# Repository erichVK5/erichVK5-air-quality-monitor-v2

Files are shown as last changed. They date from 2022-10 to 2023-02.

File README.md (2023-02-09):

# erichVK5-air-quality-monitor-v2
A leaner version of the original erichVK5 air quality monitor

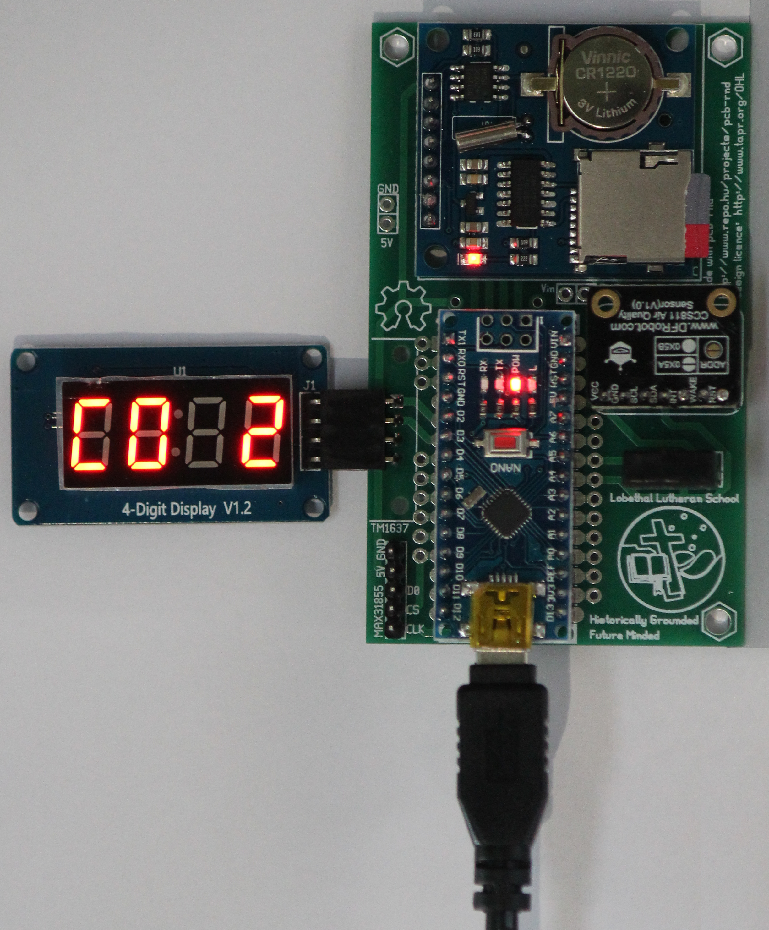
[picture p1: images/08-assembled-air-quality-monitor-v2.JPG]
assembled board


The PCB and accompanying software allow the CCS811 sensor to be used to monitor CO2 and total volatile organic compounds, and the AM2320 sensor allows humidity and temperature to be recorded as well.

This is a leaner version of https://github.com/erichVK5/erichVK5-air-quality-monitor, achieving a significant cost reduction by using an Arduino nano and a compact Deek Robot 8122 RTC/SD board on a custom PCB which also mounts the DF Robot CCS811 CO2/VOC sensor board and the AM2320 temperature/humidity sensor. 

current schematic

The revised v2 PCB was designed in pcb-rnd and simplifies the connections between the TM1637 display, CCS811 sensor, AM2320 sensor and Arduino Nano. The PCB dimensions have been carefully chosen to allow efficient panelisation on standard panel sizes if ordering larger quantities from PCB suppliers. By mounting the sensors, RTC, data logging and Arduino subassemblies on a single PCB, the build cost can be roughly halved. 

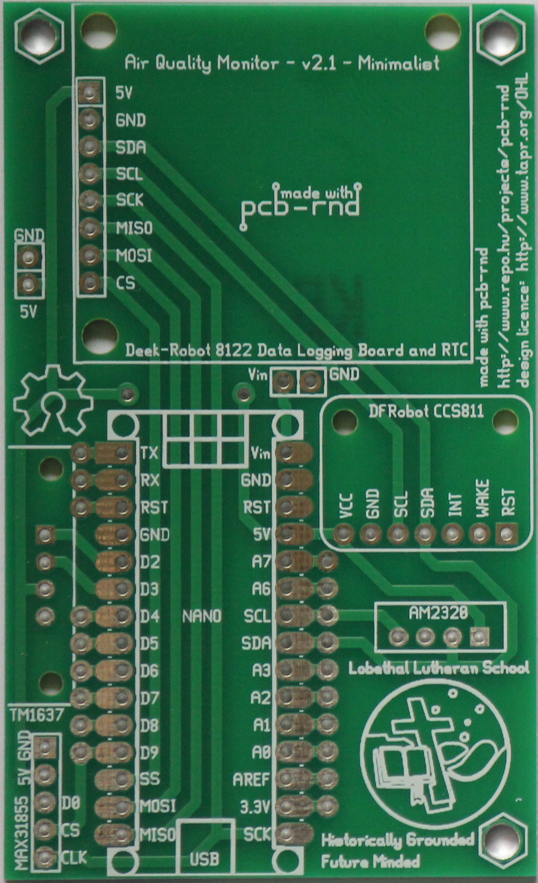
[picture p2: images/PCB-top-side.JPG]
PCB top side

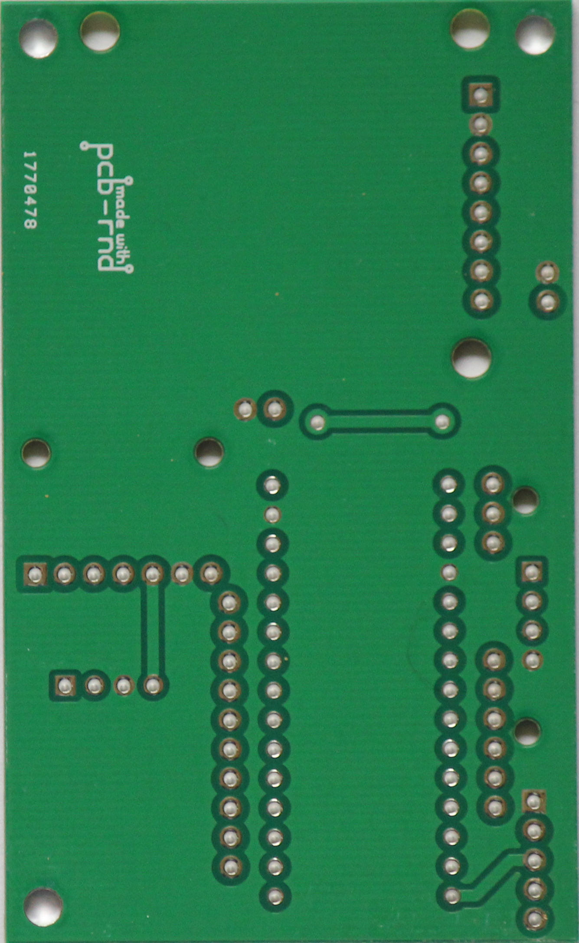
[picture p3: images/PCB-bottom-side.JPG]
PCB bottom side


The board is code compatible with the original air quality monitor, except for the real time clock, which uses a DS1307 instead of a PCF8523. The board has been designed to allow the option of mounting an Arduino Nano Every, but care must be taken if there are plans to use an external 5V power supply for the board, as the Arduino Nano Every, unlike the Arduino Nano, can apparently backfeed 5V down an inserted USB cable to a host.

Low cost data logging air quality monitors remain useful in educational and community settings to provide a qualitative indication of air quality over time. In particular, CO2 levels can be a useful proxy for air turnover in built environments, and by extension, inform measures that seek to reduce the risk of persisting airborne pathogens. The utility of CO2 as a proxy for airborne pathogen loads will be affected by sources of combustion or fermentation (i.e. processes producing CO2 in addition to people) in the indoor space, and by the use of air purifying devices, such as those circulating air through suitable filters.

The PCB has a footprint allowing connection to an inexpensive TM1637 based four digit LED display for the display of readings, but with suitable code modification, other display options are possible. For example, here is a build using a MAX7219 based 8x32 LED Matrix:

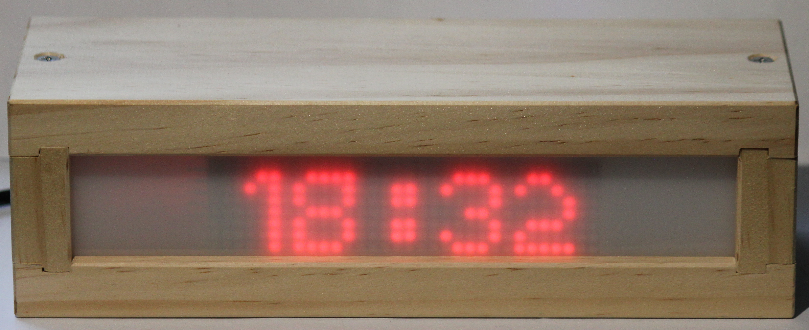
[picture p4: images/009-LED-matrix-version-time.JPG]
LED matrix version


After assembly of the PCB headers and sub-boards is complete, following the pictorial guide in the images subdirectory, a battery can be installed on the Deek Robot 8122 datalogging board. The DS1307 clock example code available within the arduino library manager can then be used to set the current time.

In addition to taking and displaying readings every 10 seconds, the accompanying code will write time stamped readings to an SD card every three minutes.

After reset, if all goes well, an initial flash screen "LLS" should appear, after which readings will be displayed sequentially, with new readings being taken every 10 seconds. Every three minutes, cached readings are written to the SD card.

The Deek Robot 8122 datalogging board requires a CR1220 battery for the DS1307 real time clock, and will require a FAT16 or FAT32 formatted SD card of between 32MB and 32GB in size.

The unit should be powered down before inserting or removing the SD card.

Data logs are written in CSV format, with sequential naming starting with LLSAQM00.CSV

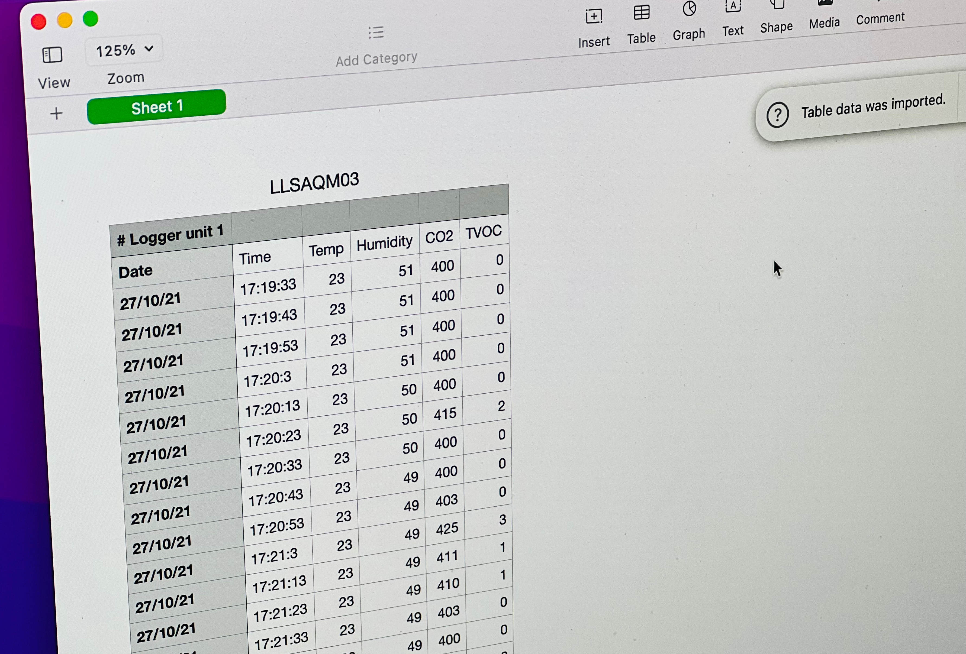
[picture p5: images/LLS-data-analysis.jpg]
data from the SD card


During operation, updated readings are displayed sequentially on the 4 digit LED display.

- Temperature readings in Centigrade are preceded by "t" on the LED display
- Humidity readings in percent are preceded by "h" on the LED display
- Carbon dioxide readings in ppm (parts per million) are preceded by "CO2" on the LED display
- Total volatile organic compound readings in ppb (parts per billion) are preceded by "tvoc" on the LED display

The code also streams results over USB as a serial device, allowing readings to be viewed as they are collected in a serial monitor in real time.

It is recommended that the CCS811 be given a 48 hour initial burn in period and be allowed 20 minutes for the sensor to warm up to provide reliable readings thereafter.

The v2 PCB layout can be opened in pcb-rnd, and gerbers for the shield have been provided in a zip file to allow ordering from the usual online PCB suppliers.

The schematic for the v2 board is essentially identical to that of the original version, with SCL using A5 and SDA using A4 on the Arduino Nano.

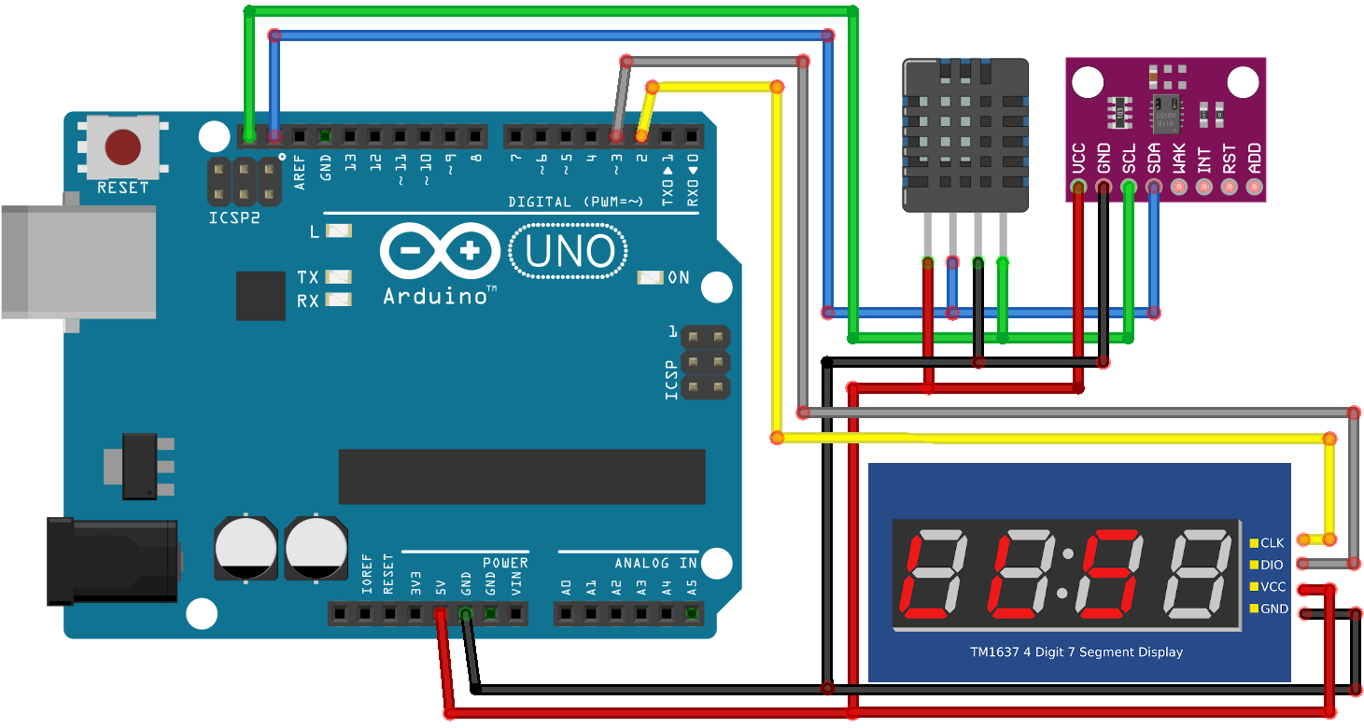
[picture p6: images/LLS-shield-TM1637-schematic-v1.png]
Shield schematic using TM1637 display


For data transfers to and from the SD card, the Deek Robot 8122 datalogging board uses SPI on the following Arduino Uno pins:

- SCK
- MISO
- MOSI
- D10 as CS (chip select)

For real time clock operations, the Deek Robot 8122 datalogging board also shares the i2c bus with with the CCS811 and AM2320 sensors, using the following pins:

- SDA(A4)
- SCL(A5)

This leaves multiple pins free on the Arduino Nano if code customisation is needed, such as for on/off signals for fans or building ventilation systems. Spare pins on the arduino nano have been broken out to pads, to allow wiring to other actuators, sensors or switches.

The v2 PCB also has pads to connect external Vin to the Arduino Nano. Builders must ensure that the overall power demands of their display and assembled unit will fall within that which can be provided by the Arduino Nano voltage regulator.

ALternatively, there is also footprint provided on the v2 PCB for a connector for provision of an external 5V supply to the 5V rail (instead of relying on USB for power) that feeds the peripherals and Arduino Nano 5V pin, BUT(!)... although a standard Arduino Nano can be powered via the 5V pin from an external source without backfeeding the voltage down the USB cable to the host, an Arduino Nano Every will apparently allow the power supplied via the 5V pin to go up the USB cable to a host, if connected.

The DS1307 real time clock seems to be a little sensitive to power supply noise. If there are issues with the clock not updating, it may be worth trying some filtering on the power supply, and/or some decoupling capacitors to smoothe the supply.

Unlike the Adafruit data logging shield which includes 10k pullup resistors for the SDA and SCL lines, they may not be as strong or may be absent on the Deek Robot 8122 datalogging board. Accordingly, for reliable operation with the clock, DF Robot and AM2320 sensors all on the same i2c bus, pullup resistors (4k7 or 10k) should be added to link Vcc to the SDA and SCL lines. A revised version of the board (v2.1) has footprints for the addition of pullup resistors if needed. 

The v2 PCB also has a footprint to allow the use of a MAX31855 thermocouple, if builders are keen to experiment with temperature measurement, display and control of various hot processes.

# LED Matrix clock build

The pins for the MAX31855 thermocouple supply most of the needed connections for an SPI driven display, such as commonly available MAX7219 LED matrices. The example build shown above uses an 8x32 MAX7219 LED matrix instead of the TM1637, connected to GND, 5v, SCK, and D9 for CS on the MAX31855 header, and MOSI (accessed on the RTC/SD board header).

A simple code example has been provided which provides some of the functionality of the TM1637 build but using a MAX7219 based 8x32 LED Matrix, along with code to read A0-A3 connected button presses to adjust the time if required. The main differences are that it does not stream results to serial, display of tvoc has not been implemented, and it does not log data to the SD card.

It displays temperature for 4 seconds, humidity for 4 seconds, CO2 for 4 seconds, and then the time for 48 seconds, after which the cycle repeats.

The LED matrix based build was conceived of as more of an example of how an inexpensive clock with environmental sensing could also be implemented with the v2 PCB, rather than simply another version of the same data logging air quality monitor. The aluminium bracket used for the switches and DC socket was surplus tile edging, and the white diffuser panel was found in a discarded fax/printer.

Again, it is worth noting that the DS1307 real time clock seems sensitive to power supply noise, so it may be worth trying some filtering on the power supply, and/or some decoupling capacitors to smoothe the supply if glitches are noted.

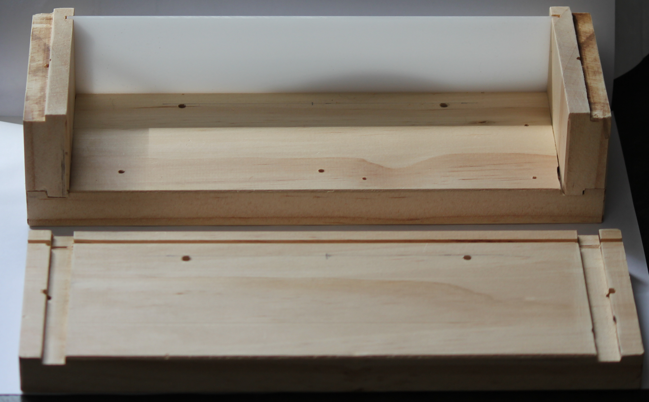
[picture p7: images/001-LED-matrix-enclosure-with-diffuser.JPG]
LED Matrix enclosure and diffuser

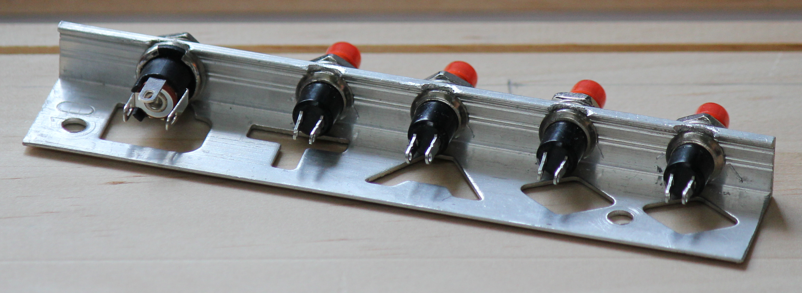
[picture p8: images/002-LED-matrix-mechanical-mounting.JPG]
LED Matrix mechanical mountings

LED Matrix mounting details
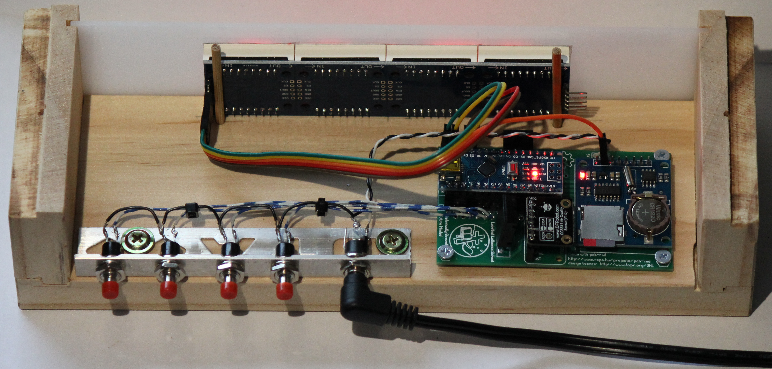
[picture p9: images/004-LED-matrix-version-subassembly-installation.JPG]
LED Matrix subassembly installation

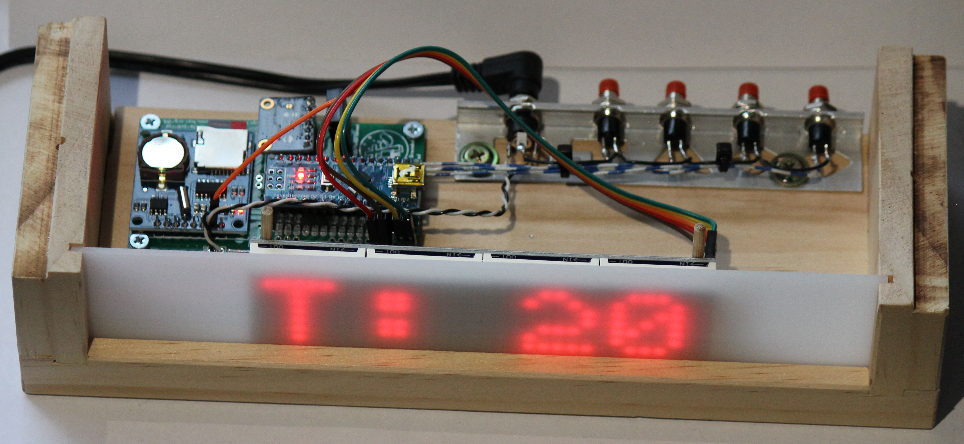
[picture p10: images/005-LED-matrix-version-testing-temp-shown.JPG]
LED Matrix testing temp

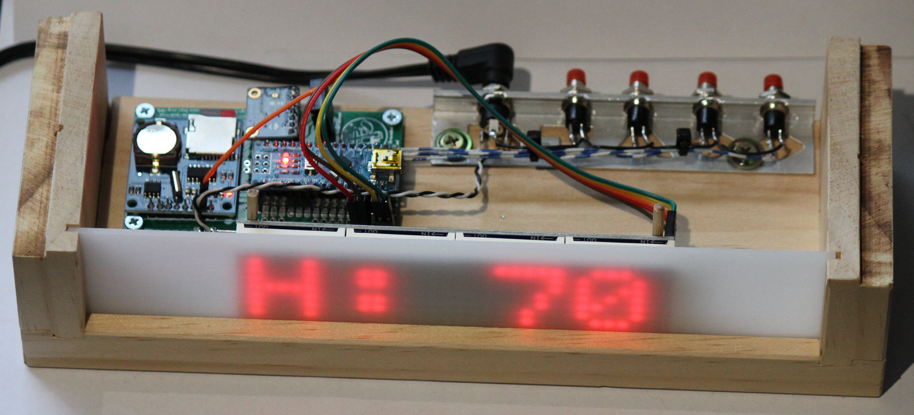
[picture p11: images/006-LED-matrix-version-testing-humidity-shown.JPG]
LED Matrix testing humidity

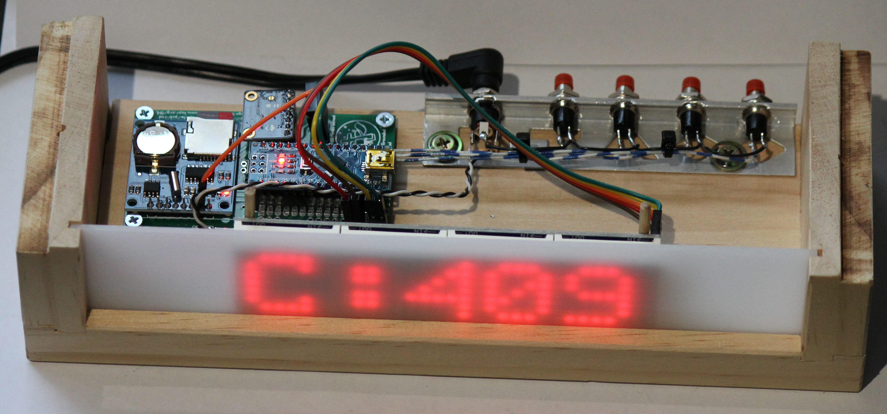
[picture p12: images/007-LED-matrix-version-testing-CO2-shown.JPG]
LED Matrix testing C02

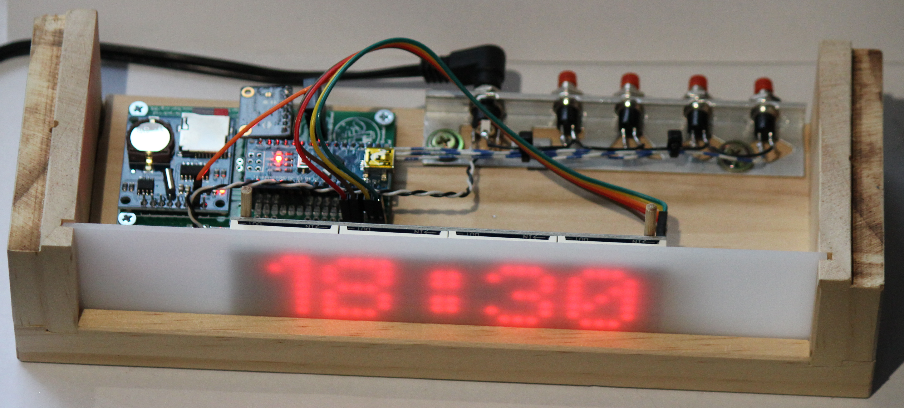
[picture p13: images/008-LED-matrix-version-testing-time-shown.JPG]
LED Matrix testing time


# Clock Drift Adjustment

The latest version of the clock code has the necessary code to adjust the real time clock (RTC) by one second every X seconds; but this requires the user to determine how fast the clock is running fast or slow.

In the prototype build, the clock ran 5.75 seconds fast every 24 hours. This was found by noting the clock ran 8 minutes 26 seconds (= 506 seconds) fast over 88 days. This allowed the number of seconds per day fast or slow (5.75 seconds), to be calculated.

Given that there are 86,400 seconds in a day, this enabled the simple calculation 86400/5.75 showing that the RTC runs one second fast every 15026.0869 seconds.

The code simply waits until 15026 seconds (the amount is defined at compile time in the code) have elapsed before subtracting one second from the RTC. It then waits 2 seconds to avoid an endless time correcting loop. If you can calculate the drift, you can now adjust the clock.

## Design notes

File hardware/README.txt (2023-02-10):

Schematic is in sch-rnd format ( see www.repo.hu/projects/sch-rnd )
PCB layout is in pcb-rnd format ( see www.repo.hu/projects/pcb-rnd )

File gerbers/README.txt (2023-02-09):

The gerbers include
- footprints for a pair of i2c bus pullup resistors
- decoupling capcitors for smoothing the 5V power rail
- increased ground plane pullback from the edges to facilitate panelisation

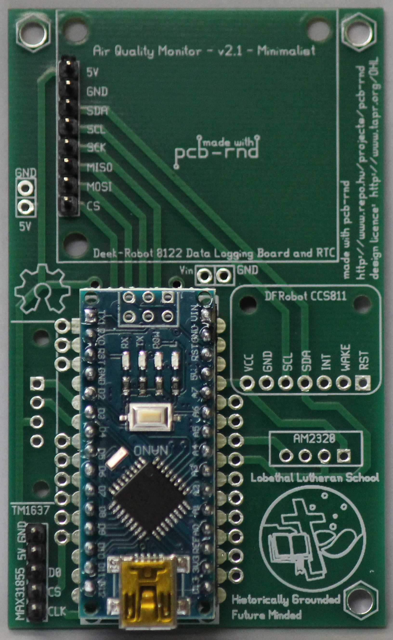
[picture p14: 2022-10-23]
images/03-add-RTC-SD-header-pins.JPG

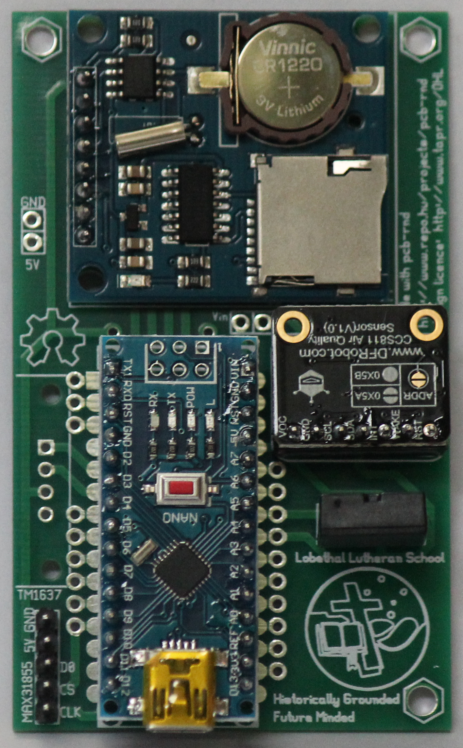
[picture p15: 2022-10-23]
images/06-add-Temp-Humidity-sensor.JPG

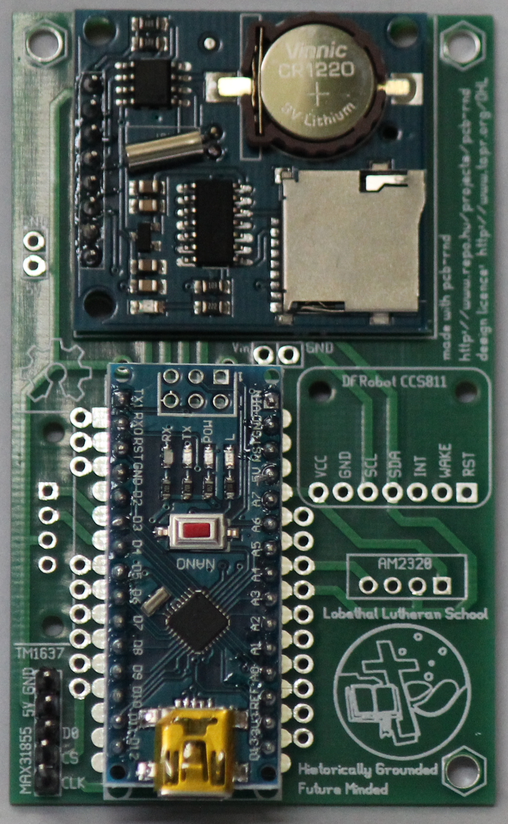
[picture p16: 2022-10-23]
images/04-add-RTC-SD-board.JPG

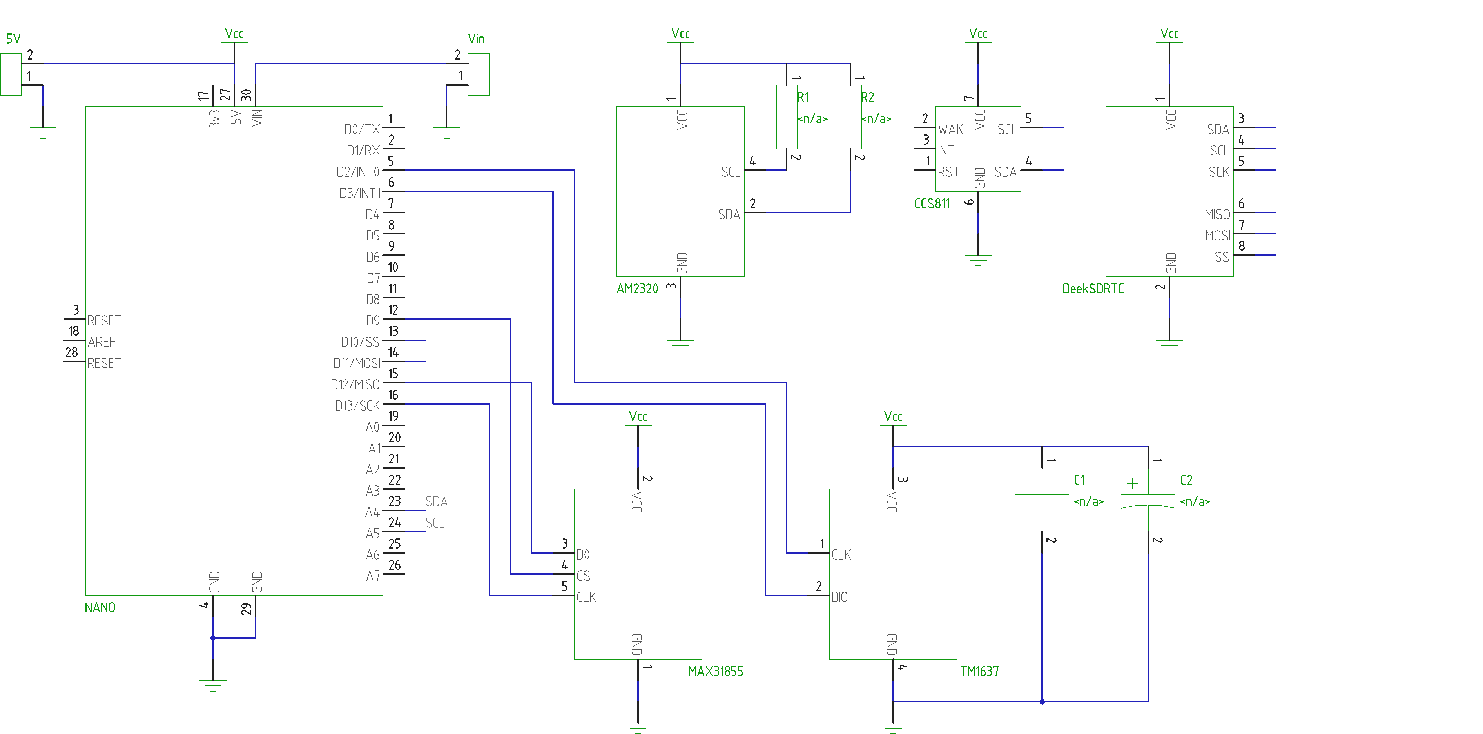
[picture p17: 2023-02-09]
images/erichVK5-AQM-v2-2.png

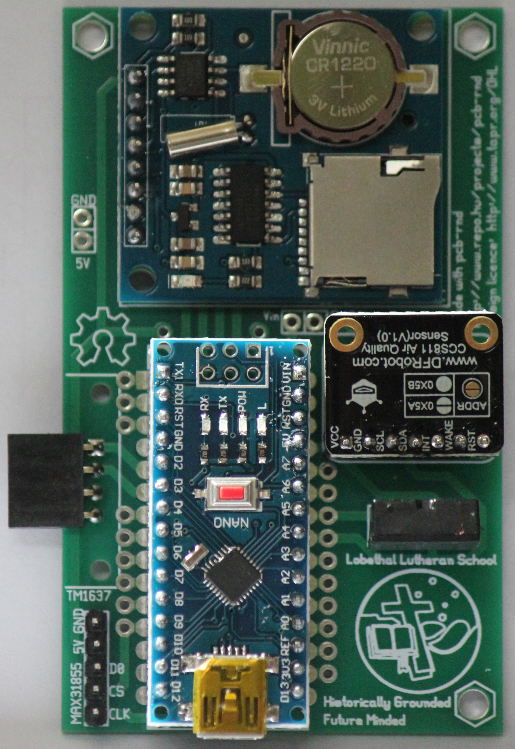
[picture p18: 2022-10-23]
images/07-add-TM1637-display-header.JPG

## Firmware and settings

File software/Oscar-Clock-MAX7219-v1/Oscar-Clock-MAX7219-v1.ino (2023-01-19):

/*
 *
 *   Copyright (C) 2022 Erich S. Heinzle
 *   
 *   drawString and drawSprite routines based on examples by Bartosz Bielawski
 *   included in LEDMatrixDriver library
 *
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
 */
 
#include "Arduino.h"
#include <LEDMatrixDriver.hpp>
#include "Adafruit_Sensor.h"
#include "Adafruit_AM2320.h"
#include "Adafruit_CCS811.h"
#include "RTClib.h"
//#include "Wire.h"
#include "SD.h"

// Pin 10 CS required by SD card code
#define CHIP_SELECT 10

// Uncomment according to your hardware type
#define HARDWARE_TYPE MD_MAX72XX::FC16_HW
//#define HARDWARE_TYPE MD_MAX72XX::GENERIC_HW

// Defining size, and output pins
#define MAX_DEVICES 4

const uint8_t LEDMATRIX_CS_PIN = 9;

const int LEDMATRIX_SEGMENTS = 4;
const int LEDMATRIX_WIDTH = LEDMATRIX_SEGMENTS * 8;

Adafruit_AM2320 am2320 = Adafruit_AM2320();
RTC_DS1307 RTC;
Adafruit_CCS811 ccs811;

// The LEDMatrixDriver class instance
LEDMatrixDriver lmd(LEDMATRIX_SEGMENTS, LEDMATRIX_CS_PIN);


void setup()
{
  pinMode(CHIP_SELECT, OUTPUT);
  pinMode(A0, INPUT_PULLUP);
  pinMode(A1, INPUT_PULLUP);
  pinMode(A2, INPUT_PULLUP);
  pinMode(A3, INPUT_PULLUP);

  lmd.setEnabled(true);
  lmd.setIntensity(0);

  // start sensors
  am2320.begin();
  ccs811.begin();
  // wait for CCS811 startup
  while(!ccs811.available());

  //Wire.begin();
  // check if RTC is working
  RTC.begin();
  if (!RTC.isrunning()) {
    ;
  }
}

/**
 * This draws a sprite to the given position using the width and height supplied (usually 8x8)
 */
void drawSprite(LEDMatrixDriver *lmd, byte* sprite, int x, int y, int width, int height )
{
  // The mask is used to get the column bit from the sprite row
  byte mask = B10000000;

  for( int iy = 0; iy < height; iy++ )
  {
    for( int ix = 0; ix < width; ix++ )
    {
      lmd->setPixel(x + ix, y + iy, (bool)(sprite[iy] & mask ));

      // shift the mask by one pixel to the right
      mask = mask >> 1;
    }

    // reset column mask
    mask = B10000000;
  }
}

/**
 * This function draws a string of the given length to the given position.
 */
void drawString(LEDMatrixDriver *lmd, char* text, int len, int x, int y )
{
  byte font[95][8] = {
                     {0,0,0,0,0,0,0,0}, // SPACE
                     {0x10,0x18,0x18,0x18,0x18,0x00,0x18,0x18}, // EXCL
                     {0x28,0x28,0x08,0x00,0x00,0x00,0x00,0x00}, // QUOT
                     {0x00,0x0a,0x7f,0x14,0x28,0xfe,0x50,0x00}, // #
                     {0x10,0x38,0x54,0x70,0x1c,0x54,0x38,0x10}, // $
                     {0x00,0x60,0x66,0x08,0x10,0x66,0x06,0x00}, // %
                     {0,0,0,0,0,0,0,0}, // &
                     {0x00,0x10,0x18,0x18,0x08,0x00,0x00,0x00}, // '
                     {0x02,0x04,0x08,0x08,0x08,0x08,0x08,0x04}, // (
                     {0x40,0x20,0x10,0x10,0x10,0x10,0x10,0x20}, // )
                     {0x00,0x10,0x54,0x38,0x10,0x38,0x54,0x10}, // *
                     {0x00,0x08,0x08,0x08,0x7f,0x08,0x08,0x08}, // +
                     {0x00,0x00,0x00,0x00,0x00,0x18,0x18,0x08}, // COMMA
                     {0x00,0x00,0x00,0x00,0x7e,0x00,0x00,0x00}, // -
                     {0x00,0x00,0x00,0x00,0x00,0x00,0x06,0x06}, // DOT
                     {0x00,0x04,0x04,0x08,0x10,0x20,0x40,0x40}, // /
                     {0x00,0x38,0x44,0x4c,0x54,0x64,0x44,0x38}, // 0
                     {0x00,0x0c,0x14,0x04,0x04,0x04,0x04,0x04}, // 1
                     {0x00,0x30,0x48,0x04,0x04,0x38,0x40,0x7c}, // 2
                     {0x00,0x38,0x44,0x04,0x18,0x04,0x44,0x38}, // 3
                     {0x00,0x04,0x0c,0x14,0x24,0x7e,0x04,0x04}, // 4
                     {0x00,0x7c,0x40,0x40,0x78,0x04,0x04,0x78}, // 5
                     {0x00,0x38,0x40,0x40,0x78,0x44,0x44,0x38}, // 6
                     {0x00,0x7c,0x04,0x04,0x08,0x08,0x10,0x10}, // 7
                     {0x00,0x3c,0x44,0x44,0x38,0x44,0x44,0x78}, // 8
                     {0x00,0x38,0x44,0x44,0x3c,0x04,0x04,0x78}, // 9
                     {0x00,0x00,0x18,0x18,0x00,0x18,0x18,0x00}, // :
                     {0x00,0x18,0x18,0x00,0x00,0x18,0x18,0x08}, // ;
                     {0x00,0x10,0x20,0x40,0x80,0x40,0x20,0x10}, // <
                     {0x00,0x00,0x7e,0x00,0x00,0xfc,0x00,0x00}, // =
                     {0x00,0x08,0x04,0x02,0x01,0x02,0x04,0x08}, // >
                     {0x00,0x38,0x44,0x04,0x08,0x10,0x00,0x10}, // ?
                     {0x00,0x30,0x48,0xba,0xba,0x84,0x78,0x00}, // @
                     {0x00,0x1c,0x22,0x42,0x42,0x7e,0x42,0x42}, // A
                     {0x00,0x78,0x44,0x44,0x78,0x44,0x44,0x7c}, // B
                     {0x00,0x3c,0x44,0x40,0x40,0x40,0x44,0x3c}, // C
                     {0x00,0x7c,0x42,0x42,0x42,0x42,0x44,0x78}, // D
                     {0x00,0x78,0x40,0x40,0x70,0x40,0x40,0x7c}, // E
                     {0x00,0x7c,0x40,0x40,0x78,0x40,0x40,0x40}, // F
                     {0x00,0x3c,0x40,0x40,0x5c,0x44,0x44,0x78}, // G
                     {0x00,0x44,0x44,0x44,0x7c,0x44,0x44,0x44}, // H
                     {0x00,0x7c,0x10,0x10,0x10,0x10,0x10,0x7e}, // I
                     {0x00,0x7e,0x02,0x02,0x02,0x02,0x04,0x38}, // J
                     {0x00,0x44,0x48,0x50,0x60,0x50,0x48,0x44}, // K
                     {0x00,0x40,0x40,0x40,0x40,0x40,0x40,0x7c}, // L
                     {0x00,0x82,0xc6,0xaa,0x92,0x82,0x82,0x82}, // M
                     {0x00,0x42,0x42,0x62,0x52,0x4a,0x46,0x42}, // N
                     {0x00,0x3c,0x42,0x42,0x42,0x42,0x44,0x38}, // O
                     {0x00,0x78,0x44,0x44,0x48,0x70,0x40,0x40}, // P
                     {0x00,0x3c,0x42,0x42,0x52,0x4a,0x44,0x3a}, // Q
                     {0x00,0x78,0x44,0x44,0x78,0x50,0x48,0x44}, // R
                     {0x00,0x38,0x40,0x40,0x38,0x04,0x04,0x78}, // S
                     {0x00,0x7e,0x10,0x10,0x10,0x10,0x10,0x10}, // T
                     {0x00,0x42,0x42,0x42,0x42,0x42,0x42,0x3e}, // U
                     {0x00,0x42,0x42,0x42,0x42,0x44,0x28,0x10}, // V
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
                      // (the font does not contain any lower case letters. you can add your own.)
  };

  for( int idx = 0; idx < len; idx ++ )
  {
    int c = text[idx] - 32;

    // stop if char is outside visible area
    if( x + idx * 6  > LEDMATRIX_WIDTH )
      return;

    // only draw if char is visible
    if( 8 + x + idx * 6 > 0 )
      drawSprite(lmd, font[c], x + idx * 6, y, 8, 8 );
  }
}

void adjustTime(LEDMatrixDriver *lmd, RTC_DS1307 *rtc, DateTime *dt) {
  int min_orig = dt->minute();
  int hr_orig = dt->hour();
  uint32_t ticks = dt->secondstime();
  int hr = hr_orig;
  int mi = min_orig;
  char strbuf[6]; // hh:mm
  sprintf(strbuf, "Set..");
  int len = strlen(strbuf);
  drawString(lmd, strbuf, len, 0, 0);
  lmd->display();   // Toggle display of the new framebuffer
  delay(1000);
  while (analogRead(A0) < 50) {
    if (analogRead(A3) < 50 && analogRead(A1) < 50) {
      mi = (mi - 1)%60;
    } else if (analogRead(A3) < 50 && analogRead(A1) > 500) {
      mi = (mi + 1)%60;    
    } else if (analogRead(A2) < 50 && analogRead(A1) < 50) {
      hr = (hr - 1)%24;
    } else if (analogRead(A2) < 50 && analogRead(A1) > 500) {
      hr = (hr + 1)%24;    
    }
    delay(200);
    sprintf(strbuf, "%02d%c%02d", hr, (true ? ':' : ' '), mi);
    int len = strlen(strbuf);
    drawString(lmd, strbuf, len, 0, 0);
  }
  rtc->adjust(DateTime(ticks+3600*(hr-hr_orig) + 60*(mi-min_orig)));
  delay(200);
  *dt = rtc->now();
}

void loop()
{
  char strbuf[6]; // hh:mm
  int len;
  int current_minute;
  int previous_minute = 0;
  uint16_t co2;
  DateTime dt = RTC.now();

  // these variable are used for adjusting the error in the RTC
  // you will need to see how many seconds slow or fast it runs over an extended
  // period to calculate the number of seconds per day it runs fast or slow
  // in the prototype, it ran 8 min 26 seconds (= 506 seconds) fast over 88 days
  // i.e. 5.75 seconds per day fast
  uint32_t ticks_orig = dt.unixtime();
  uint32_t ticks_current = 0;
  uint16_t ticks_since_adjustment = 0;
  uint16_t ticks_per_adjustment = 15026; // if running 5.75 seconds fast per day
  int ticks_adjustment = 1;              // i.e 5.75 seconds every 86,400 seconds ( = day)
  
  int use_sensors = 1;
  int adjust_error = 0; // set this to 1 if you plan to adjust RTC drift error
  
  while (1)
  {
    dt = RTC.now();
    current_minute = dt.minute();
    ticks_current = dt.unixtime();
    if (adjust_error) {
      ticks_since_adjustment = (ticks_current - ticks_orig)%ticks_per_adjustment;
      if (ticks_since_adjustment >= (ticks_per_adjustment - 3)) { // allow a 2 second window
        RTC.adjust(DateTime(ticks_current - ticks_adjustment));
        delay(3000); // avoid endless readjustment in a loop
      }
    }
    delay(200);
    if (current_minute != previous_minute)
    {
      if (use_sensors) {
       sprintf(strbuf, "T: %02d", (int)am2320.readTemperature());
       len = strlen(strbuf);
       drawString(&lmd, strbuf, len, 0, 0);
       lmd.display();   // Toggle display of the new framebuffer
       delay(4000);
       sprintf(strbuf, "H: %02d", (int)am2320.readHumidity());
       len = strlen(strbuf);
       drawString(&lmd, strbuf, len, 0, 0);
       lmd.display();   // Toggle display of the new framebuffer
       delay(4000);
       if(ccs811.available()){
         if(!ccs811.readData()){
           co2 = (uint16_t)ccs811.geteCO2();
           if (co2 < 1000) {
             sprintf(strbuf, "C:%03d", co2);
           } else {
             sprintf(strbuf, "C%04d", co2);
           }
           len = strlen(strbuf);
           drawString(&lmd, strbuf, len, 0, 0);
           lmd.display();   // Toggle display of the new framebuffer
           delay(4000);
         }
        }
      }
      sprintf(strbuf, "%02d%c%02d", dt.hour(), (true ? ':' : ' '), current_minute);
      len = strlen(strbuf);
      drawString(&lmd, strbuf, len, 0, 0);
      lmd.display();   // Toggle display of the new framebuffer
      delay(5000);
      previous_minute = current_minute;
    }
    // now to see if the time needs adjusting
    // this only works if buttons are attached to A0...A3
    if (0 && analogRead(A0) < 50) {
      delay(50); // software debouncing 
      if (analogRead(A0) < 50) {
        sprintf(strbuf, "A0..");
        len = strlen(strbuf);
        drawString(&lmd, strbuf, len, 0, 0);
        lmd.display();
        delay(500);
        adjustTime(&lmd, &RTC, &dt);
        current_minute = dt.minute();
        sprintf(strbuf, "%02d%c%02d", dt.hour(), (true ? ':' : ' '), dt.minute());
        len = strlen(strbuf);
        drawString(&lmd, strbuf, len, 0, 0);
        lmd.display();   // Toggle display of the new framebuffer
      }
    }
  }
}

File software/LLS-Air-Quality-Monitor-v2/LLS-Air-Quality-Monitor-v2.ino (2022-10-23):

/*
 *
 *   Copyright (C) 2021 Erich S. Heinzle
 *   Website https://github.com/Lobethal-Lutheran-School/
 *   
 *   Lobethal Lutheran School - "Historically Grounded, Future Minded"
 *
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
 */
 
#include "Arduino.h"
#include "TM1637Display.h"
#include "Adafruit_Sensor.h"
#include "Adafruit_AM2320.h"
#include "Adafruit_CCS811.h"
#include "RTClib.h"
#include "Wire.h"
#include "SD.h"

// TM1637 Module connection pins (Digital Pins)
#define CLK 2
#define DIO 3
// Pin 10 CS required by SD card code
#define CHIP_SELECT 10

// Time (milliseconds) between sensor readings
// need 8*DISPLAY_PAUSE < MS_BETWEEN_SAMPLES 
#define DISPLAY_PAUSE 1200 

// NB caching more than 18 sample sets tends to exceed
// dynamic RAM needs of code running on atmega328
// so writing batches of 18 samples to SD is about right
//
#define MS_BETWEEN_SAMPLES 10000
// samples per minute = 60000/MS_BETWEEN_SAMPLES 
#define SAMPLES_PER_WRITE 18
// minutes between sample writes to SD = SAMPLES_PER_WRITE/samples per minute 

// Struct used for storing time stamp for a set of readings
typedef struct time_stamp_t {
  uint8_t Year;
  uint8_t Month;
  uint8_t Day;
  uint8_t Hour;
  uint8_t Min;
  uint8_t Sec;
};  

// Struct used for caching sets of readings between SD card writes
typedef struct ring_buffer_t {
  time_stamp_t time_stamp[SAMPLES_PER_WRITE];
  uint8_t temp[SAMPLES_PER_WRITE];     // essentially guaranteed to be less than 256
  uint8_t humidity[SAMPLES_PER_WRITE]; // less than 101 by definition
  uint16_t co2[SAMPLES_PER_WRITE];     // usually exceeds 256
  uint16_t tvoc[SAMPLES_PER_WRITE];    // may exceed 256
  uint8_t index;
};

// four digit definition for "LLS"
const uint8_t SEG_LLS[] = {
  SEG_D | SEG_E | SEG_F,                           // L
  SEG_D | SEG_E | SEG_F,                           // L
  SEG_A | SEG_C | SEG_D | SEG_F | SEG_G,           // S
  0
  };

// four digit definition for "CO2"
const uint8_t SEG_CO2[] = {
  SEG_A | SEG_D | SEG_E | SEG_F,                   // C
  SEG_A | SEG_B | SEG_C | SEG_D | SEG_E | SEG_F,   // O
  0,
  SEG_A | SEG_B | SEG_D | SEG_E | SEG_G            // 2
  };

// four digit definition for "t" - temperature
const uint8_t SEG_T[] = {
  SEG_D | SEG_E | SEG_F | SEG_G,                   // t
  0,
  0,
  0
  };

// four digit definition for "h" - humidity
const uint8_t SEG_H[] = {
  SEG_C | SEG_E | SEG_E | SEG_F | SEG_G,           // h
  0,
  0,
  0
  };

// four digit definition for "TVOC" - total VOCs
const uint8_t SEG_TVOC[] = {
  SEG_D | SEG_E | SEG_F | SEG_G,                   // t
  SEG_C | SEG_D | SEG_E,                           // v
  SEG_C | SEG_D | SEG_E | SEG_G,                   // o
  SEG_D | SEG_E | SEG_G,                           // c
  };

// four digit definition for "SD" - writes to SD card
const uint8_t SEG_SD[] = {
  SEG_A | SEG_C | SEG_D | SEG_F | SEG_G,           // S
  SEG_B | SEG_C | SEG_D | SEG_E | SEG_G,           // d
  0,
  0
  };

TM1637Display display(CLK, DIO);
Adafruit_AM2320 am2320 = Adafruit_AM2320();
Adafruit_CCS811 ccs811;
RTC_DS1307 RTC;
//RTC_PCF8523 RTC; use this for V1 PCB and dataloggin shield
File logfile;

// mathematics using unsigned long can cope with rollover
const unsigned long samplingPeriodMillis = MS_BETWEEN_SAMPLES;

void setup()
{
    pinMode(CHIP_SELECT, OUTPUT);  
    // open serial port to stream data
    Serial.begin(57600);

    // start sensors
    am2320.begin();
    ccs811.begin();

    // wait for CCS811 startup
    while(!ccs811.available());

    // check if SD card is present and working
    if (!SD.begin(CHIP_SELECT)) {
      Serial.println("SD init failure/not present");
      return;
    } else {
      Serial.println("# SD initialised");
    }

    // create new, incrementally numbered filename
    char filename[] = "LLSAQM00.CSV";
    for (uint8_t i = 0; i < 100; i++) {
      filename[6] = i/10 + '0';
      filename[7] = i%10 + '0';
      // open the new file if it does not exist, then leave loop
      if (!SD.exists(filename)) {
        logfile = SD.open(filename, FILE_WRITE);
        Serial.print("# Created logfile: ");
        Serial.println(filename);
        logfile.println("# Logger unit 1");
        logfile.println("Date,Time,Temp,Humidity,CO2,TVOC");
        break;
      }
    }

    // check that logfile was successfully created
    if (!logfile) {
      Serial.println("Failed to create logfile");
      return;
    }

    Wire.begin();
    // check if RTC is working
    if (!RTC.begin()) {
      logfile.println("RTC failed");
      Serial.println("RTC failed");
    }
    Serial.println("# Completed setup");
    Serial.println("Date,Time,Temp,Humidity,CO2,TVOC");

}

// Routine to display latest set of readings from cached values on LED display
void display_readings(ring_buffer_t *ring_buffer) {
  display.setSegments(SEG_T);
  delay(DISPLAY_PAUSE);
  display.showNumberDec(ring_buffer->temp[ring_buffer->index], false);
  delay(DISPLAY_PAUSE);
  display.setSegments(SEG_H);
  delay(DISPLAY_PAUSE);
  display.showNumberDec(ring_buffer->humidity[ring_buffer->index], false);
  delay(DISPLAY_PAUSE);
  display.setSegments(SEG_CO2);
  delay(DISPLAY_PAUSE);
  display.showNumberDec(ring_buffer->co2[ring_buffer->index], false);
  delay(DISPLAY_PAUSE);
  display.setSegments(SEG_TVOC);
  delay(DISPLAY_PAUSE);
  display.showNumberDec(ring_buffer->tvoc[ring_buffer->index], false);
  delay(DISPLAY_PAUSE);
}

// Routine to write cached readings to SD card
void write_ring_buffer_if_full(ring_buffer_t *ring_buffer) {
  int i;
  if(ring_buffer->index == SAMPLES_PER_WRITE) {
    display.setSegments(SEG_SD);
    for(i = 0; i < SAMPLES_PER_WRITE; i++) {
      logfile.print(ring_buffer->time_stamp[i].Day);
      logfile.print('/');
      logfile.print(ring_buffer->time_stamp[i].Month);
      logfile.print('/');
      logfile.print(ring_buffer->time_stamp[i].Year);
      logfile.print(',');
      if (ring_buffer->time_stamp[ring_buffer->index].Hour < 10) {
        logfile.print('0');
      }
      logfile.print(ring_buffer->time_stamp[i].Hour);
      logfile.print(':');
      if (ring_buffer->time_stamp[ring_buffer->index].Min < 10) {
        logfile.print('0');
      }
      logfile.print(ring_buffer->time_stamp[i].Min);
      logfile.print(':');
      if (ring_buffer->time_stamp[ring_buffer->index].Sec < 10) {
        logfile.print('0');
      }
      logfile.print(ring_buffer->time_stamp[i].Sec);
      logfile.print(',');
      logfile.print(ring_buffer->temp[i]);
      logfile.print(',');
      logfile.print(ring_buffer->humidity[i]);
      logfile.print(',');
      logfile.print(ring_buffer->co2[i]);
      logfile.print(',');
      logfile.println(ring_buffer->tvoc[i]);
      logfile.flush();
    }
    // reset index to zero to start filling cache from beginning again
    ring_buffer->index = 0;  
    Serial.println("# Samples->SD");
  }
}
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

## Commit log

2022-10-23 Add PCB and construction sequence images
2022-10-23 Add build pictures for LED matrix version
    Example shows construction with MAX7219 based 8x32 LED matrix module with four additional pushbutton switches for inputs on A0-A3
2022-11-08 Discuss pullup resistors for the SDA and SCL lines
2023-01-12 Clock drift adjustment code added
    [Oscar-Clock-MAX7219-v1.ino]
2023-01-13 Fix modular arithmetic for clock adjustment
    ticks_per_adjustment is congruent to zero with division modulo ticks_per_adjustment, so ticks_since_adjustment can never equal or exceed ticks_per_adjustment
    [Oscar-Clock-MAX7219-v1.ino]
2023-01-14 Fix unix time vs time since Jan 1 2000
    [Oscar-Clock-MAX7219-v1.ino]
2023-01-19 Fix off by seconds from 1970->2000 error
    [Oscar-Clock-MAX7219-v1.ino]
2023-02-09 Create gerber README file
2023-02-09 v2.2 gerbers added to repository
    [erichVK5-AQM-v2-2.GBL, erichVK5-AQM-v2-2.GBO, erichVK5-AQM-v2-2.GBS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]
2023-02-09 Add latest schematic in png and svg formats
2023-02-09 Add latest schematic to README
2023-02-10 Add schematic and layout

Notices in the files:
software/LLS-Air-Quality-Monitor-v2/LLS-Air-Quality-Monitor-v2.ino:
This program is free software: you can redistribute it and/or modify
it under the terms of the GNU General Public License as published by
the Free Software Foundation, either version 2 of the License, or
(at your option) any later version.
